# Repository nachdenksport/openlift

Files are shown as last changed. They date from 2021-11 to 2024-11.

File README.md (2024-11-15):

# OpenLift

## What is it?

OpenLift is an open router lift for small routers.

## Info and documentation

Currently only German documentation is available.

* [German](https://openlift.nachdenksport.de/)

## Community

* YouTube : [Nachdenksport YouTube channel](https://youtube.com/c/nachdenksport)
* GitHub : [github.com/nachdenksport](https://github.com/nachdenksport)

## Support my work

The OpenLift project is made possible by the awesome supporters of the [Nachdenksport YouTube channel](https://youtube.com/c/nachdenksport) and [Web-Shop](https://nachdenksport.de/). Without you, it wouldn't be possible to develop such a project. :heart:

## Community projects

* Improved hand crank by XTramp : [Open on Printables](https://www.printables.com/model/906361-kurbel-fur-fraslift-openlift)

## License

All files in this repository are licensed under the GPLv3 license (unless otherwise noted). Here is a quick summary; for more details please check the LICENSE file.

What you __can__ do:
  * Modify
  * Distribute
  * Private and commercial use

What you __must__ do:
  * Include license and copyright notice  
  * Share source files
  * Use the same license (GPLv3)
  * Document changes applied

Note: STL and STEP files are generally not source files. The source files are those you use to design your project such as CAD files (Fusion 360), mechanical drawings, code, documentation, etc. However, STL and STEP files are a commonly used format with great interoperability. Therefore, we encourage to share the STL and STEP files in addition to the source files.

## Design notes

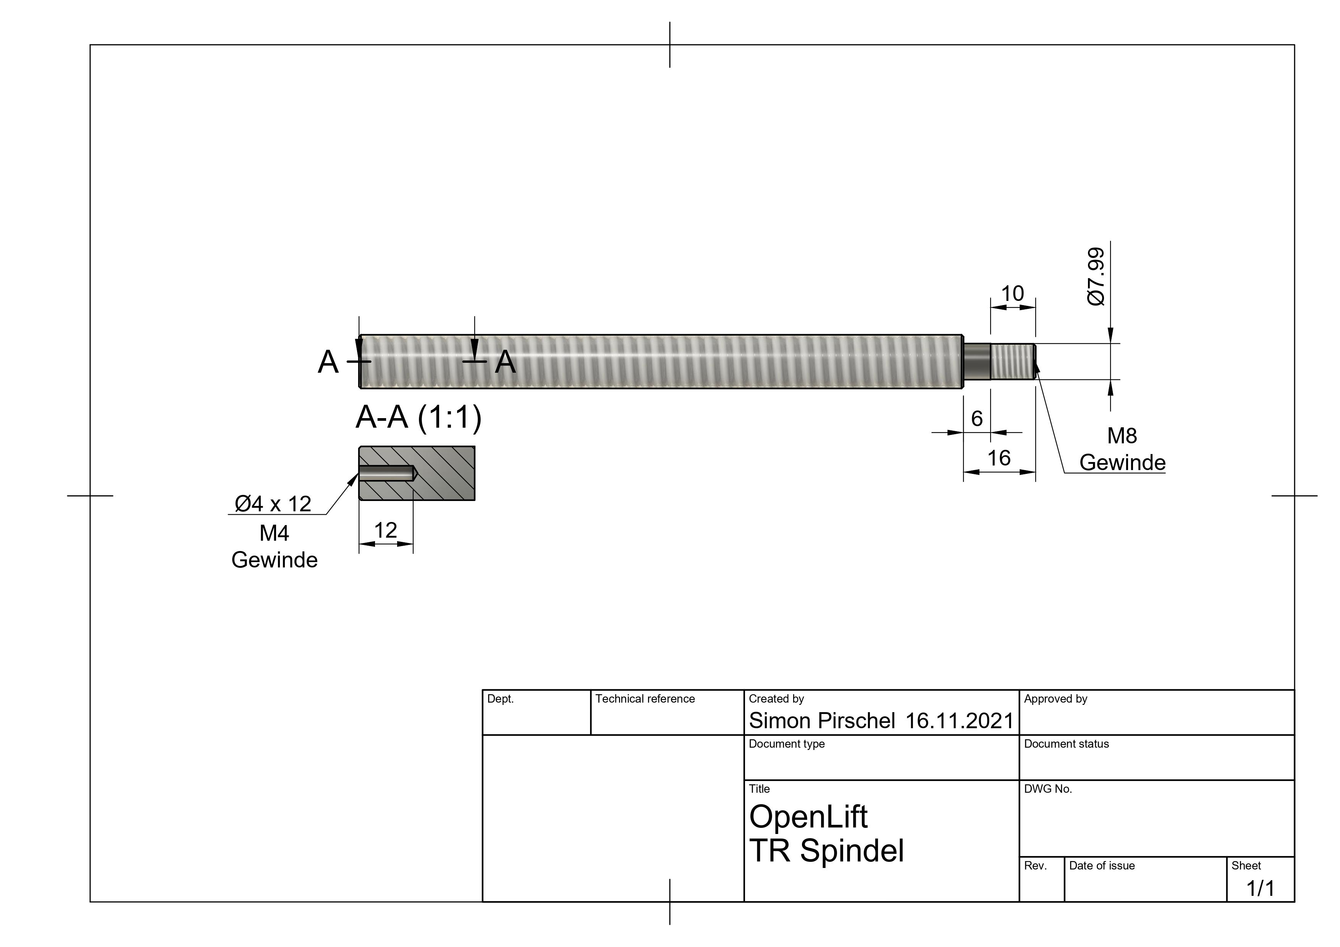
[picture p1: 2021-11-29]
images/OpenLift-TRSpindel_150mm-v1.jpg

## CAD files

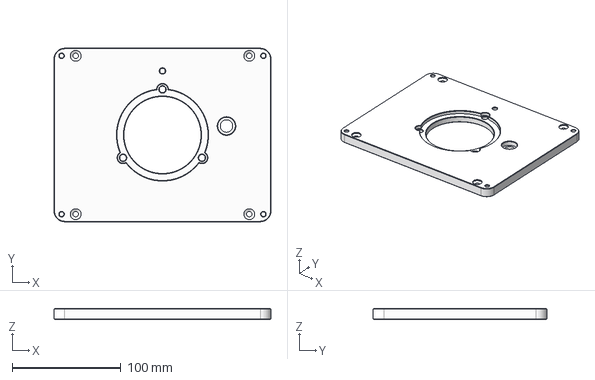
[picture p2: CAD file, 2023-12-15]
CAD/Einlegeplatte v1.3.step
200.0 x 160.0 x 10.0 mm

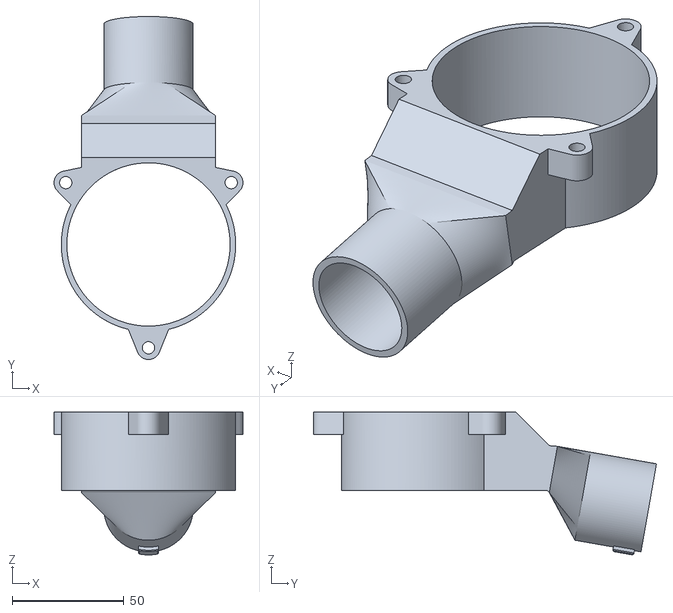
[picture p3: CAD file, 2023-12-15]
STL/Absaugung/Absaugschuh.stl
84.5 x 153.4 x 63.9

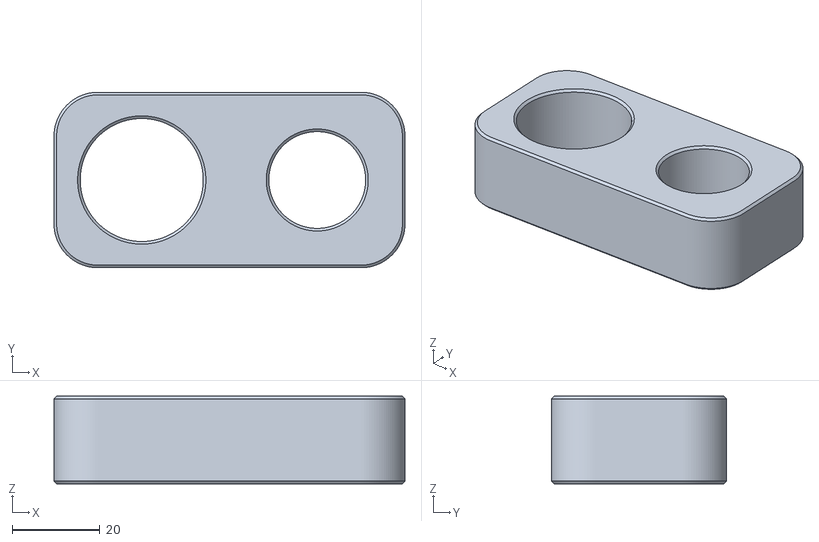
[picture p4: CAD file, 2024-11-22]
STL/Fraeslift/v1.4/Scaling-Helper.stl
80.0 x 40.0 x 20.0

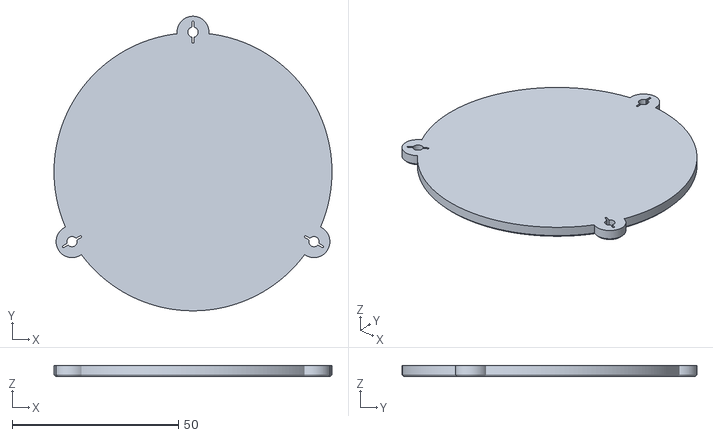
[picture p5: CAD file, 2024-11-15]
STL/Reduzierringe/v1.4/Closed - Reduzierring v1.4.stl
83.6 x 88.6 x 3.45

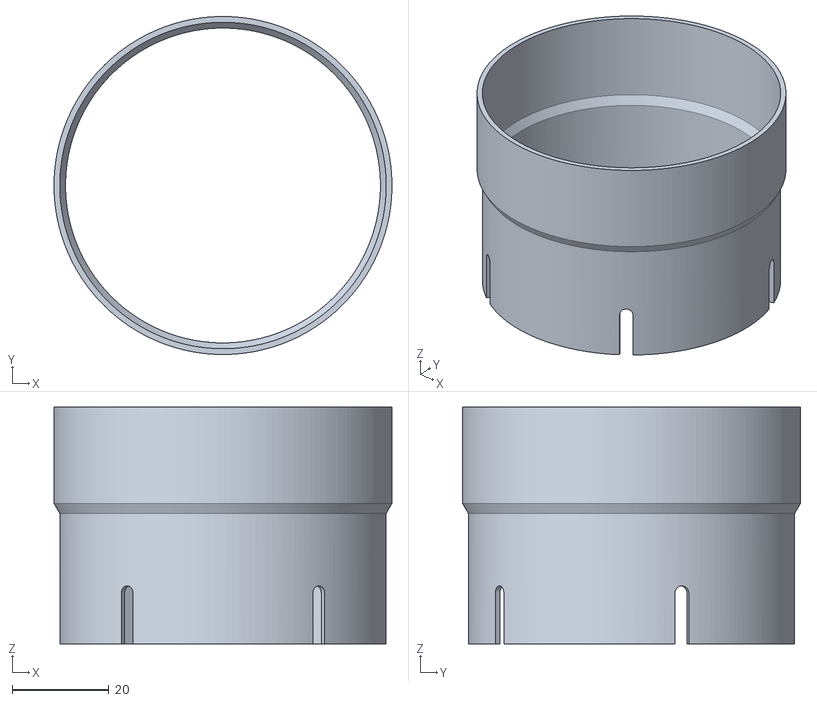
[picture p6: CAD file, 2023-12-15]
STL/Absaugung/SpindelManschette-Makita.stl
70.0 x 70.0 x 49.0

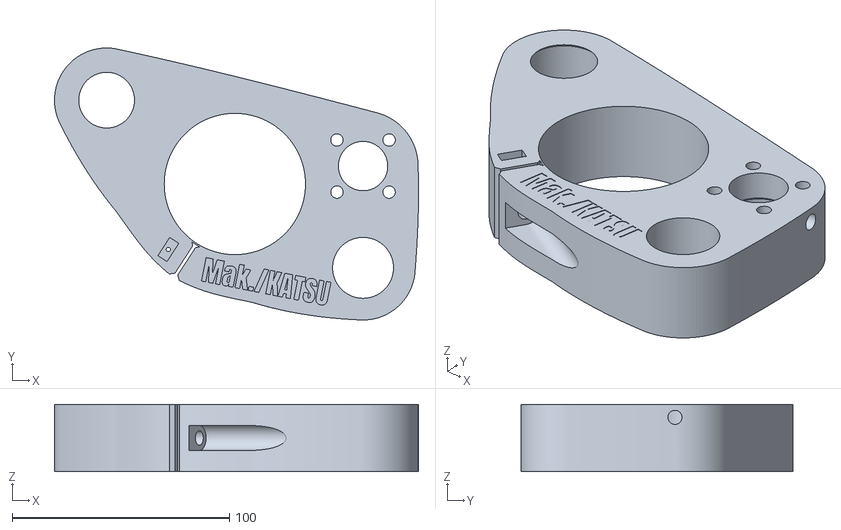
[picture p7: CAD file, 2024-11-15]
STL/Fraeslift/v1.4/Haupthalter-Makita-KeinAufmaß.stl
167.5 x 125.2 x 31.0

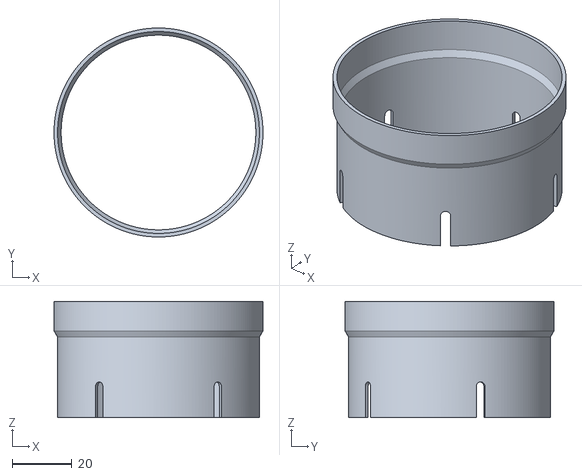
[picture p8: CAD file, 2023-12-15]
STL/Absaugung/SpindelManschette-Makita-kurz.stl
70.0 x 70.0 x 39.0

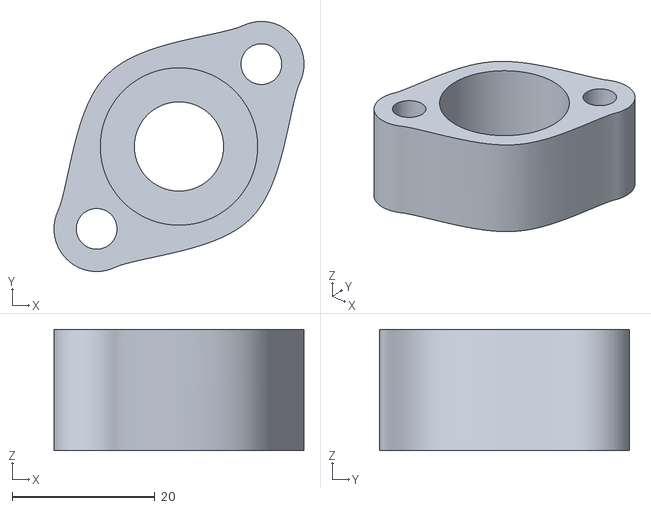
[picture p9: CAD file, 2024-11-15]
STL/Fraeslift/v1.4/Spindellagerhalter-KeinAufmaß.stl
35.0 x 35.0 x 17.0

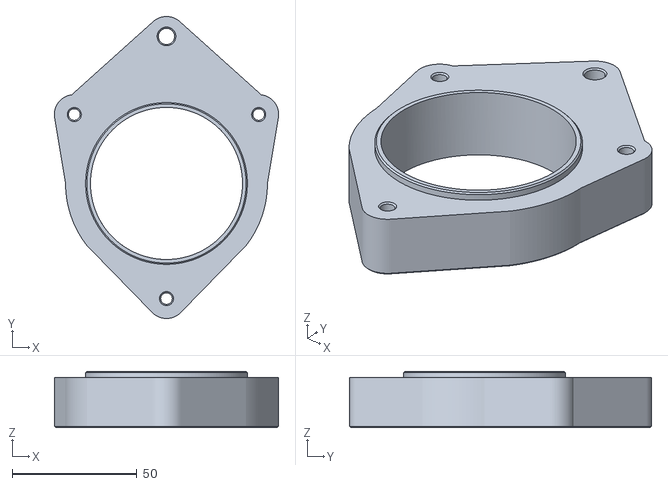
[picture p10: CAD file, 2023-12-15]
STL/Absaugung/Absaugung-Bohrschablone-v1.0.stl
90.0 x 121.2 x 22.5

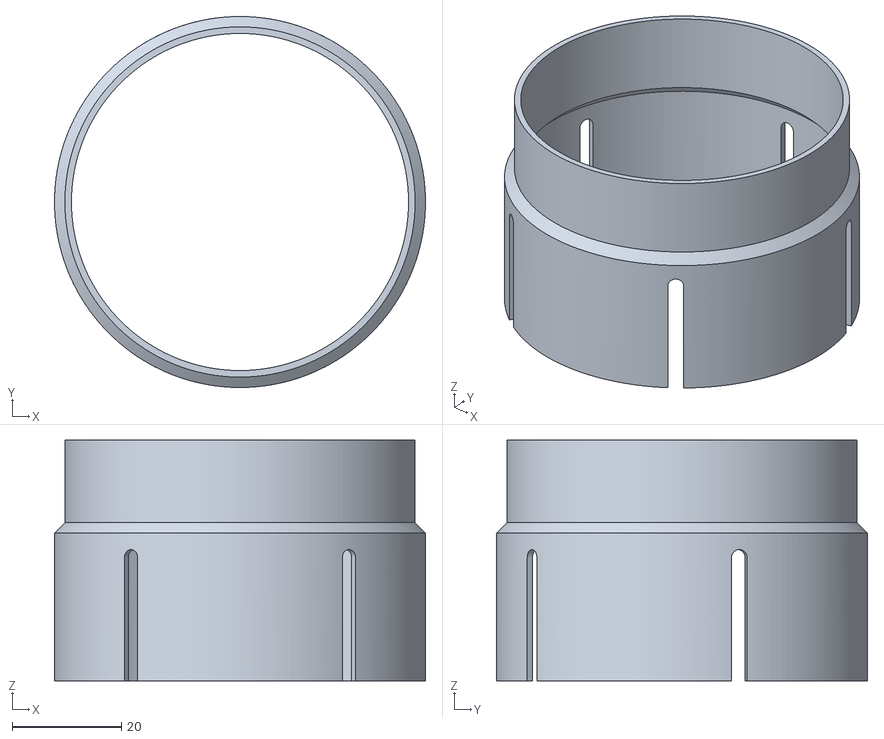
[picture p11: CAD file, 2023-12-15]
STL/Absaugung/SpindelManschette-Makita-v1.0.stl
67.8 x 67.8 x 44.0

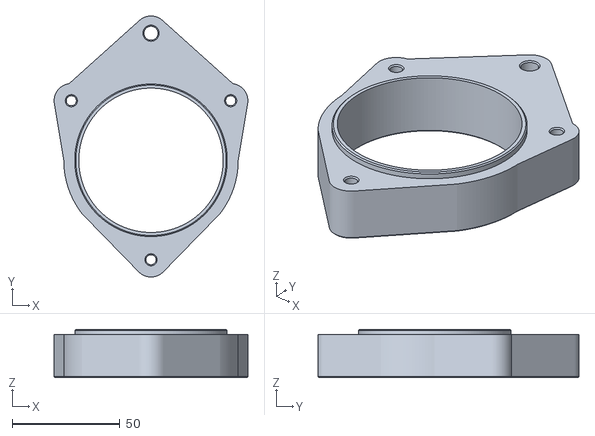
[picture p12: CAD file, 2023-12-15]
STL/Absaugung/Absaugung-Bohrschablone-v1.1-v1.2.stl
90.0 x 121.2 x 22.5

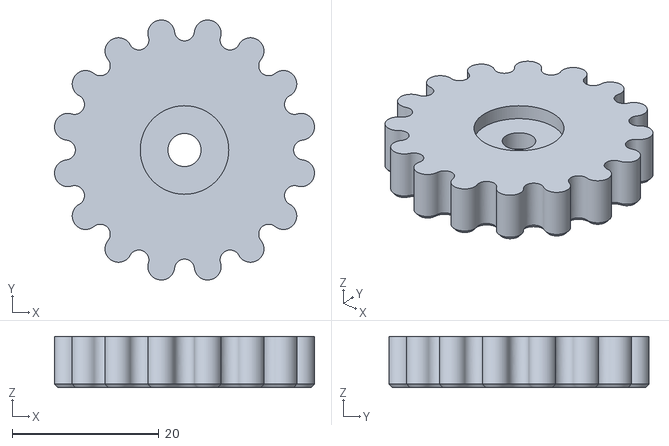
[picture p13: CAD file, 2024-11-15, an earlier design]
STL/Fraeslift/v1.3/LeitspindelSterngriff.stl
35.4 x 35.4 x 7.00

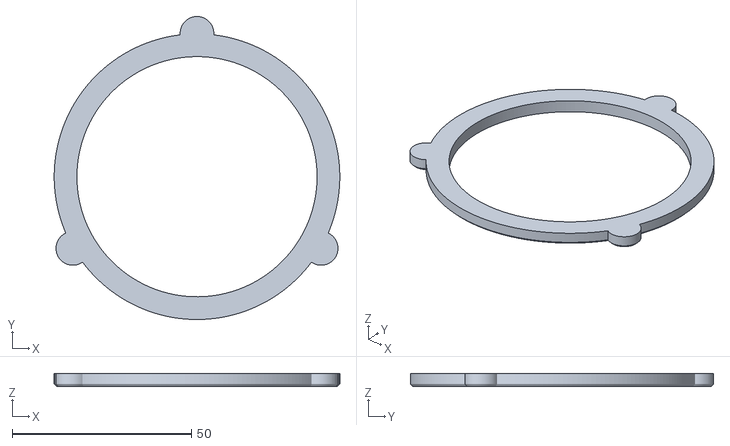
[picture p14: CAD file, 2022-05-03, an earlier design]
STL/Reduzierringe/v1.0/67mm - Reduzierring v1.0.stl
79.7 x 84.5 x 3.50

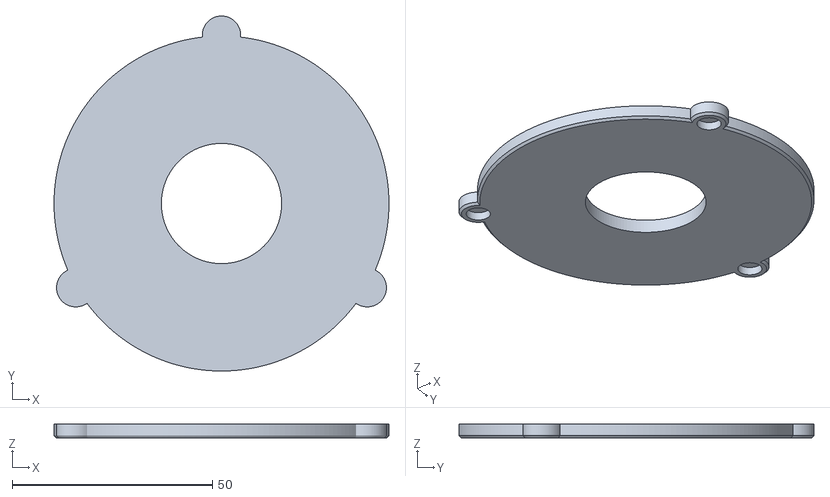
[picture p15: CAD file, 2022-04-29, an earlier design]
STL/Reduzierringe/v1.1/30mm - Reduzierring v1.1.stl
83.6 x 88.6 x 3.50

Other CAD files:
STL/Reduzierringe/v1.2/30mm - Reduzierring v1.2.stl
STL/Reduzierringe/v1.3/30mm - Reduzierring v1.3.stl
CAD/Einlegeplatte v1.2.step
STL/Fraeslift/v1.3/Handkurbel.stl
CAD/Einlegeplatte v1.0.step
CAD/Einlegeplatte v1.1.step
STL/Fraeslift/v1.3/Feinjustierung DeWalt.stl
STL/Fraeslift/v1.3/Haupthalter BoschGKF600.stl
STL/Fraeslift/v1.3/Haupthalter DeWalt D26203.stl
STL/Fraeslift/v1.3/Haupthalter MakitaRT0700.stl
STL/Fraeslift/v1.3/Haupthalter ShaperOriginSM1.stl
STL/Fraeslift/v1.3/HuelsenmutterLager.stl
STL/Fraeslift/v1.3/KleinerSterngriff.stl
STL/Fraeslift/v1.3/Spindellagerhalter.stl
STL/Fraeslift/v1.3/SpindellagerhalterLagerSpacer.stl
STL/Fraeslift/v1.3/StellringHalter.stl
STL/Fraeslift/v1.3/StellringHalterLinearfuehrung.stl
STL/Fraeslift/v1.3/Sterngriff.stl
STL/Reduzierringe/v1.0/30mm - Reduzierring v1.0.stl
STL/Reduzierringe/v1.0/45mm - Reduzierring v1.0.stl
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

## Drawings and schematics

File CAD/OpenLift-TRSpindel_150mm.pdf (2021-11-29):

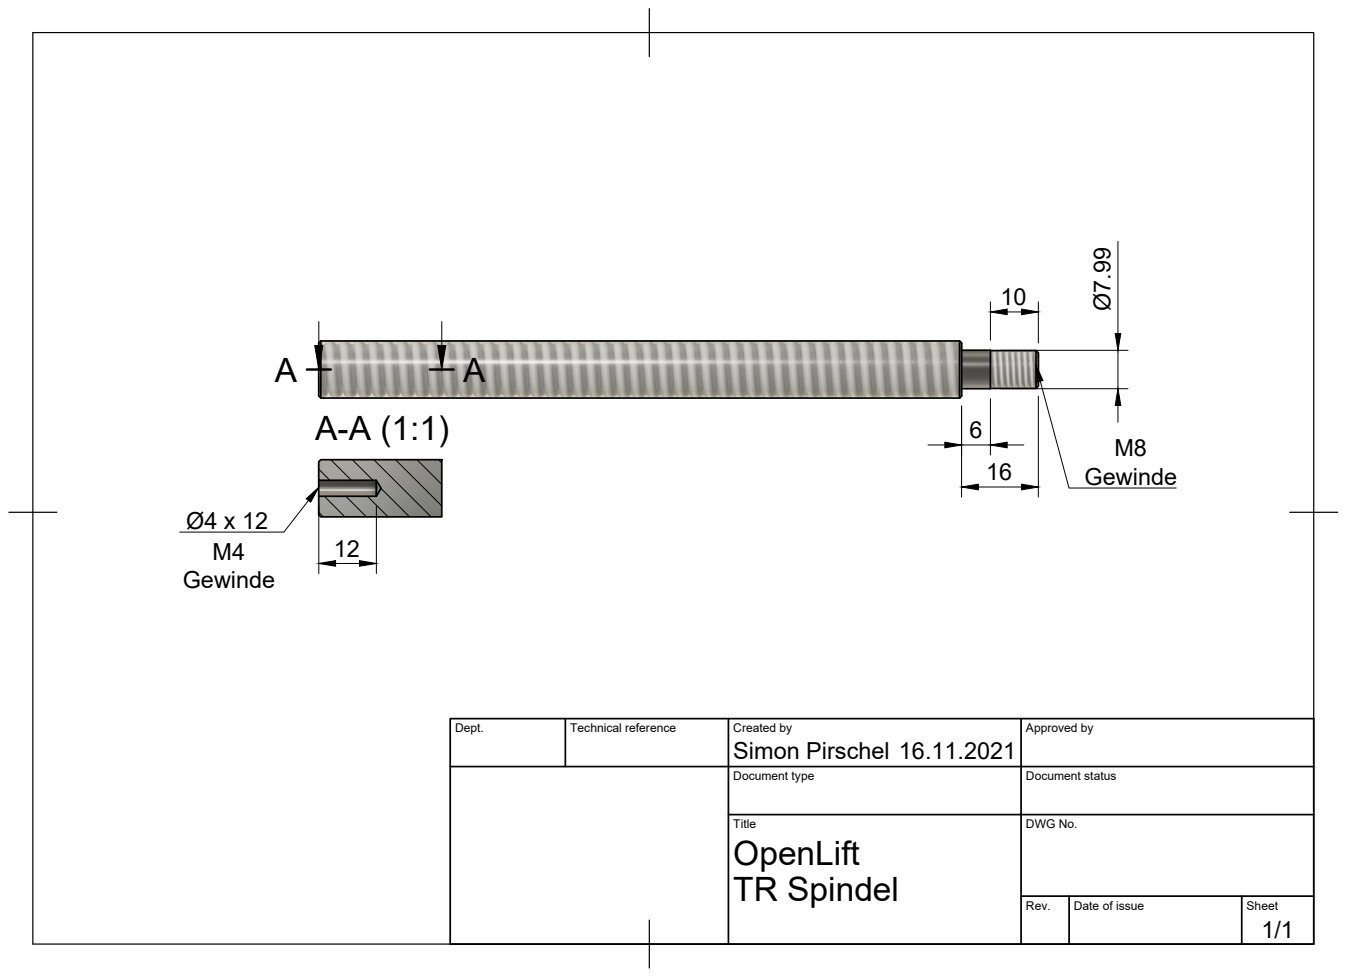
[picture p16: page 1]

Dept. | Technical reference | Created by Simon Pirschel 16.11.2021 | Approved by

Document type | Document status

Title OpenLift TR Spindel | DWG No.

Rev. | Date of issue | Sheet 1/1

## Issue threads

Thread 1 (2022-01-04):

Reduzierring Einlegeplatte - Poka Yoke

Bullnados, 2022-01-04:
Du stellst mit den unterschiedlichen Magnetpolen sicher, das der Ring nicht falsch eingesetzt werden kann.
Wenn du aber eine Nubsi hinzufügst un die nicht symmetrisch machst, kannst du die Platte nur in eine Weiße einlegen

So mal schnell hingeschmiert, geht mit etwas nachdenken auch schöner
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

nachdenksport, 2022-01-12:
Danke für den Vorschlag. Die Lösung durch die Polung funktioniert gut und muss daher nicht geändert werden.

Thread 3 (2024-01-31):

6x6 Magnete ab 1.2 - Gründe und Befestigung

janschroeter, 2024-01-31:
Hi Simon,

in Version 1.2 hast du die Aufnahme für die Magnete in der Platte, laut Changelog, auf durchgängige Bohrungen geändert und 6x6 Magnete vorgesehen. Leider finden sich dort keine Informationen über die Gründe für diese Änderung. Kannst du diese ggf. etwas weiter erläutern? Auch konnte ich keine näheren Informationen über die dann vorgesehene Befestigung der Magnete in der Platte finden. Das Aufbau-Anleitungs-Video bezieht sich derzeit ja noch auf 1.1. Ich würde diese einfach einkleben, aber würde natürlich gern auch keine Fehler bei der Montage machen, welche sich durch einfaches Nachfragen vermeiden ließen.

Ich habe seit langer Zeit eine bisher unmontierte 1.1 Platte rumliegen und werde diese, vor dem nun endlich anstehenden Einbau, mit Montagebohrungen für die Absaugung versehen. Die Frage die sich mir stellt ist, ob ich auch gleich noch die Bohrungen für die Magnete in der Platte anpasse um sozusagen auf 1.3 zu aktualisieren.

MfG Jan

nachdenksport, 2024-01-31:
Moin Jan,

die Bohrungen waren vorher Sacklöcher und beim Einkleben der Magnete gab es öfter Probleme, weil Luft zwischen Magnet und Bohrungsboden nicht entweichen konnte. Die Durchgangsbohrungen haben dieses Problem behoben. Ein weiterer Grund war, dass dadurch größere Magnete genutzt werden konnten mit mehr Haltekraft und im Reduzierring wiederum kleinere Magnete. Das hat ermöglicht das lästige Schleifen der Reduzierringe zu beseitigen. Die 6x6 Magnete werden seit den Durchgangsbohrungen auch nicht mehr mit Sekundenkleber, sondern mit hochfestem Schraubenkleber. Damit hat man mehrere Stunden Zeit die Position noch zu korrigieren und Fehler beim einkleben können eigentlich nicht mehr passieren.

Wenn du bei einer v1.1 Platte einfach ein kleines Loch in die 3 Sacklochbohrungen der Magnete bohrst hast du den gleichen Effekt, wie bei den aktuellen Platten. 1mm Durchmesser reicht schon.

Closed 2024-01-31.

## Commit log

2021-11-29 zeichnung leitspindel pdf und jpg
2021-11-29 3d model einlegeplatte
    [Einlegeplatte.step]
2022-04-29 neue Reduzieringe fuer v1.0
    [30mm - Reduzierring v1.0.stl, 45mm - Reduzierring v1.0.stl, 67mm - Reduzierring v1.0.stl]
2022-04-29 v1.1 Reduzierringe
    [30mm - Reduzierring v1.1.stl, 45mm - Reduzierring v1.1.stl, 67mm - Reduzierring v1.1.stl]
2022-04-29 ezcad2 lite dateien fuer lasermarkierung
2022-04-29 neue haupthalter aus v1.1 und feinjustierung fuer dewalt spindel
    [Feinjustierung DeWalt.stl, Haupthalter BoschGKF600.stl, Haupthalter DeWalt D26203.stl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]
2022-04-29 v1.0 Haupthalter neuem namensschema angepasst
    [Haupthalter MakitaRT0700.stl]
2022-04-29 neue v1.1 CAD daten
    [Einlegeplatte v1.0.step, Einlegeplatte v1.1.step]
2022-04-29 Handkurbel Hohehnverstellung
    [Handkurbel.stl]
2022-05-03 falsche kontour referenzen bei v1.0 einlegeringen
    [30mm - Reduzierring v1.0.stl, 45mm - Reduzierring v1.0.stl, 67mm - Reduzierring v1.0.stl]
2023-05-16 new files for v1.2
    [30mm - Reduzierring v1.2.stl, 45mm - Reduzierring v1.2.stl, 67mm - Reduzierring v1.2.stl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]
2023-06-12 10% kleinerer Sterngriff für Leitspindel
    Die Makita XGT ("40v") Akku-Fräse RT001G hat scheinbar eine leicht größere Akku-Aufnahme, als die anderen Modelle, so dass der originale Griff am Fräser-Gehäuse ansteht.
    Diese Variante mit 2mm kleinerem Sterngriff-Radius löst das Problem, und ist immer noch griffig genug. Siehe Vergleich-Fotos: https://imgur.com/a/AdVjSun
    Ich habe die STEP files nicht angepasst.
    [LeitspindelSterngriff.stl]
2023-12-15 durchgangsbohrung magnete, befestigungsloecher absaugung
    [Einlegeplatte v1.3.step]
2023-12-15 klemmung fuer 3x3 magnete
    [30mm - Reduzierring v1.3.stl, 45mm - Reduzierring v1.3.stl, 67mm - Reduzierring v1.3.stl]
2024-11-15 move STL files to new subfolder
    [Feinjustierung DeWalt.stl, Handkurbel.stl, Haupthalter BoschGKF600.stl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]
2024-11-15 new v1.4 files
    [Closed - Reduzierring v1.4.stl, Haupthalter-Makita-KeinAufmaß.stl, Spindellagerhalter-KeinAufmaß.stl]
2024-11-22 helper tool to find scale factore for printer-material combi for unscaled parts
    [Scaling-Helper.stl]
